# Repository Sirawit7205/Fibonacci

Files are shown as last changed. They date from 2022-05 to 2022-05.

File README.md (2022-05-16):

# Fibonacci
16-bit Fibonacci calculator with logic ICs

A circuit that calculates fibonacci up to 46,368 using only logic chips (except the display).

This project is mostly intended as a soldering practice because the PIC microcontroller featured on the board is fully capable of calculating fibonacci anyway without all the logic chips.

There are two versions of PCB, through-hole and SMD. Both versions use the same circuit and have the same physical size (4x6 inches: will fit most postcard frames).

The only difference is the PIC microcontroller used, both code also work the same way.

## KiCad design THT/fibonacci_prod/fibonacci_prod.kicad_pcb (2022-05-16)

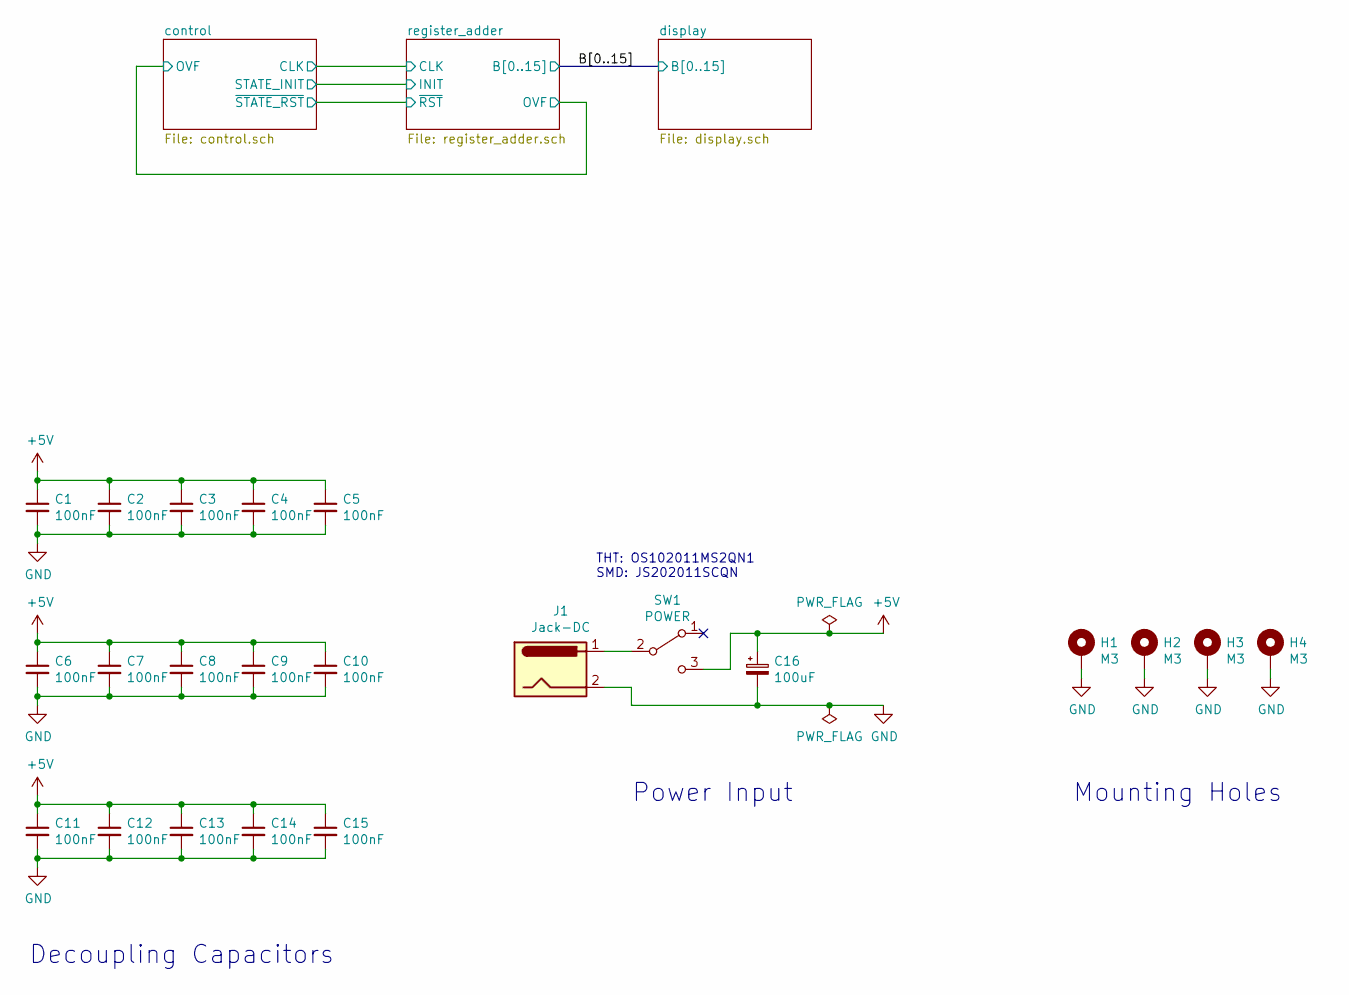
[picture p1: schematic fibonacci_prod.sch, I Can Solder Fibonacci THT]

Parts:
C1, C2, C3, C4, C5, C6, C7, C8, C9, C10, C11, C12, C13, C14, C15: 100nF; C_Disc_D5.1mm_W3.2mm_P5.00mm
C16: 100uF; CP_Radial_D6.3mm_P2.50mm
H1, H2, H3, H4: M3; MountingHole_3mm_Pad
J1: Jack-DC; BarrelJack_Horizontal
SW1: POWER; OS102011MS2QN1

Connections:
+5V: C1.1, C2.1, C3.1, C4.1, C5.1, C6.1, C7.1, C8.1, C9.1, C10.1, C11.1, C12.1, C13.1, C14.1, C15.1, C16.1, SW1.3 (C); also elsewhere on the board
GND: C1.2, C2.2, C3.2, C4.2, C5.2, C6.2, C7.2, C8.2, C9.2, C10.2, C11.2, C12.2, C13.2, C14.2, C15.2, C16.2, H1.1, H2.1, H3.1, H4.1, J1.2; also elsewhere on the board
unnamed: J1.1, SW1.2 (B)

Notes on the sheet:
Decoupling Capacitors
Power Input
THT: OS102011MS2QN1 SMD: JS202011SCQN
Mounting Holes

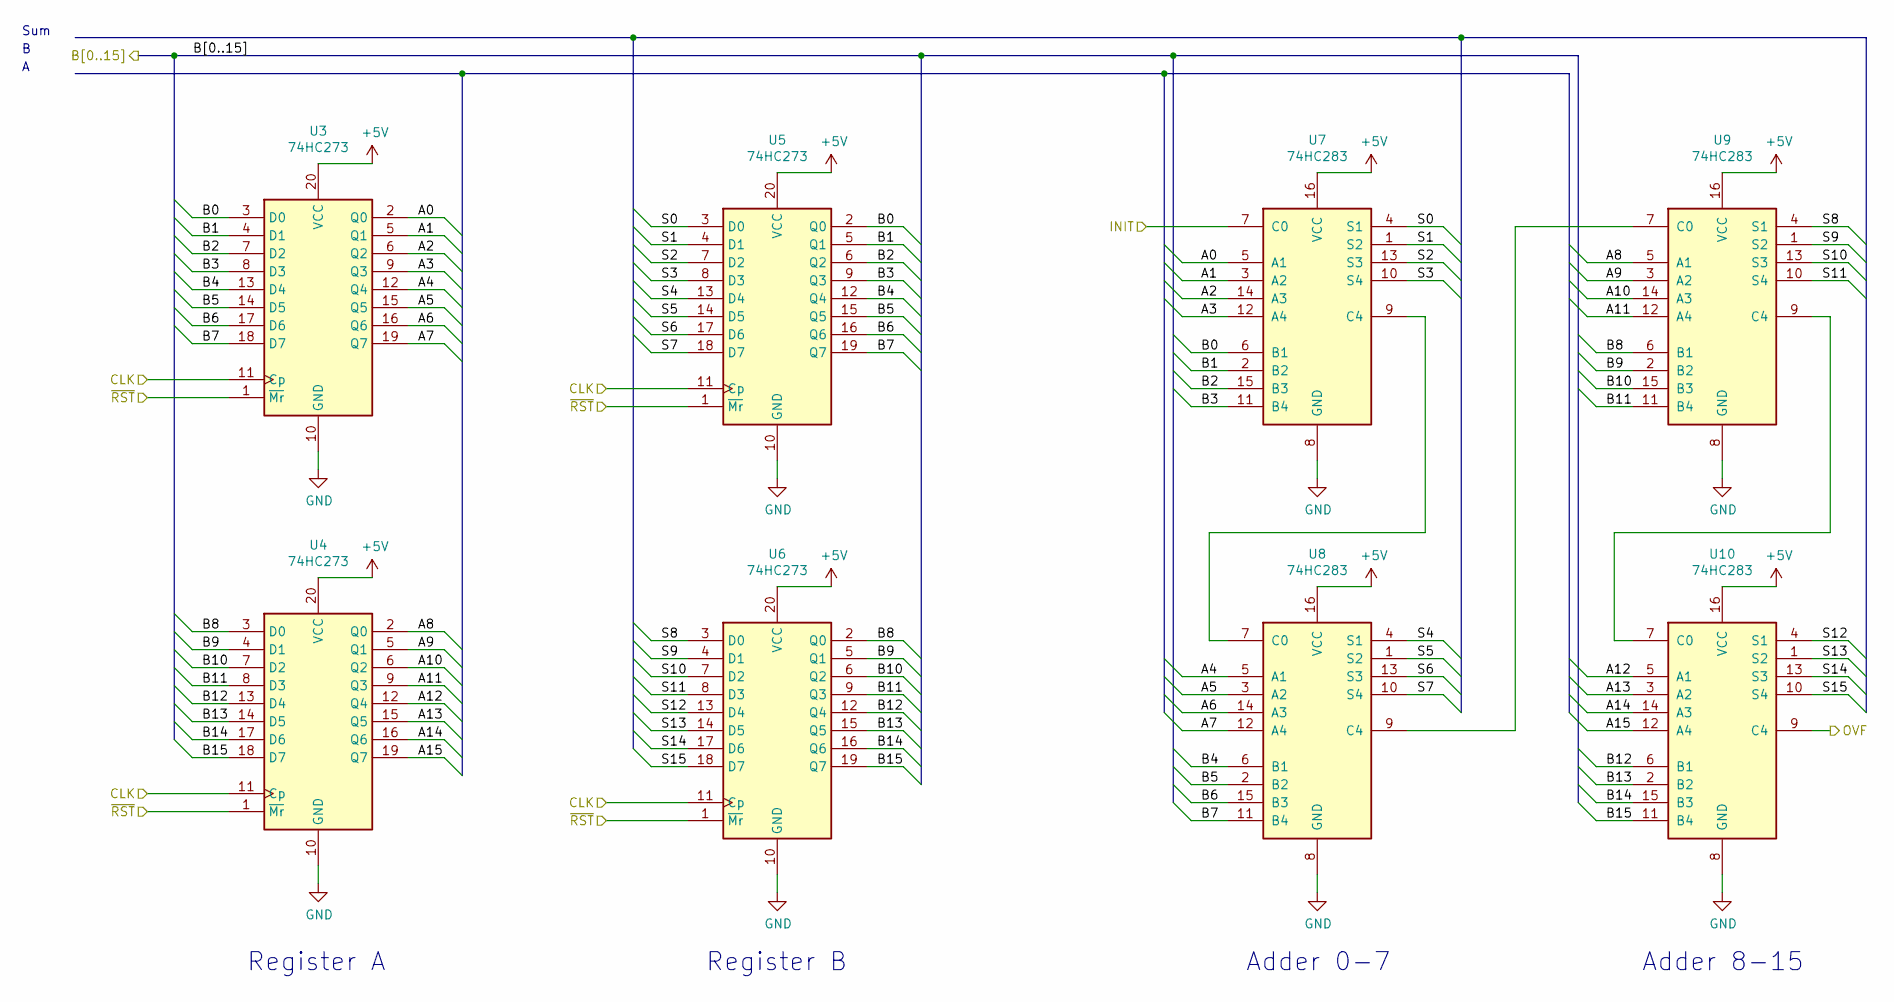
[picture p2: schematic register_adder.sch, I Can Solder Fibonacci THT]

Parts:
U3, U4, U5, U6: 74HC273; DIP-20_W7.62mm
U7, U8, U9, U10: 74HC283; DIP-16_W7.62mm

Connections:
+5V: U3.20 (VCC), U4.20 (VCC), U5.20 (VCC), U6.20 (VCC), U7.16 (VCC), U8.16 (VCC), U9.16 (VCC), U10.16 (VCC); also elsewhere on the board
/control/CLK: U3.11 (Cp), U4.11 (Cp), U5.11 (Cp), U6.11 (Cp); also elsewhere on the board
/control/OVF: U10.9 (C4); also elsewhere on the board
/display/B0: U3.3 (D0), U5.2 (Q0), U7.6 (B1); also elsewhere on the board
/display/B1: U3.4 (D1), U5.5 (Q1), U7.2 (B2); also elsewhere on the board
/display/B2: U3.7 (D2), U5.6 (Q2), U7.15 (B3); also elsewhere on the board
/display/B3: U3.8 (D3), U5.9 (Q3), U7.11 (B4); also elsewhere on the board
/display/B4: U3.13 (D4), U5.12 (Q4), U8.6 (B1); also elsewhere on the board
/display/B5: U3.14 (D5), U5.15 (Q5), U8.2 (B2); also elsewhere on the board
/display/B6: U3.17 (D6), U5.16 (Q6), U8.15 (B3); also elsewhere on the board
/display/B7: U3.18 (D7), U5.19 (Q7), U8.11 (B4); also elsewhere on the board
/display/B8: U4.3 (D0), U6.2 (Q0), U9.6 (B1); also elsewhere on the board
/display/B9: U4.4 (D1), U6.5 (Q1), U9.2 (B2); also elsewhere on the board
/display/B10: U4.7 (D2), U6.6 (Q2), U9.15 (B3); also elsewhere on the board
/display/B11: U4.8 (D3), U6.9 (Q3), U9.11 (B4); also elsewhere on the board
/display/B12: U4.13 (D4), U6.12 (Q4), U10.6 (B1); also elsewhere on the board
/display/B13: U4.14 (D5), U6.15 (Q5), U10.2 (B2); also elsewhere on the board
/display/B14: U4.17 (D6), U6.16 (Q6), U10.15 (B3); also elsewhere on the board
/display/B15: U4.18 (D7), U6.19 (Q7), U10.11 (B4); also elsewhere on the board
/register_adder/A0: U3.2 (Q0), U7.5 (A1)
/register_adder/A1: U3.5 (Q1), U7.3 (A2)
/register_adder/A2: U3.6 (Q2), U7.14 (A3)
/register_adder/A3: U3.9 (Q3), U7.12 (A4)
/register_adder/A4: U3.12 (Q4), U8.5 (A1)
/register_adder/A5: U3.15 (Q5), U8.3 (A2)
/register_adder/A6: U3.16 (Q6), U8.14 (A3)
/register_adder/A7: U3.19 (Q7), U8.12 (A4)
/register_adder/A8: U4.2 (Q0), U9.5 (A1)
/register_adder/A9: U4.5 (Q1), U9.3 (A2)
/register_adder/A10: U4.6 (Q2), U9.14 (A3)
/register_adder/A11: U4.9 (Q3), U9.12 (A4)
/register_adder/A12: U4.12 (Q4), U10.5 (A1)
/register_adder/A13: U4.15 (Q5), U10.3 (A2)
/register_adder/A14: U4.16 (Q6), U10.14 (A3)
/register_adder/A15: U4.19 (Q7), U10.12 (A4)
/register_adder/INIT: U7.7 (C0); also elsewhere on the board
/register_adder/S0: U5.3 (D0), U7.4 (S1)
/register_adder/S1: U5.4 (D1), U7.1 (S2)
/register_adder/S2: U5.7 (D2), U7.13 (S3)
/register_adder/S3: U5.8 (D3), U7.10 (S4)
/register_adder/S4: U5.13 (D4), U8.4 (S1)
/register_adder/S5: U5.14 (D5), U8.1 (S2)
/register_adder/S6: U5.17 (D6), U8.13 (S3)
/register_adder/S7: U5.18 (D7), U8.10 (S4)
/register_adder/S8: U6.3 (D0), U9.4 (S1)
/register_adder/S9: U6.4 (D1), U9.1 (S2)
/register_adder/S10: U6.7 (D2), U9.13 (S3)
/register_adder/S11: U6.8 (D3), U9.10 (S4)
/register_adder/S12: U6.13 (D4), U10.4 (S1)
/register_adder/S13: U6.14 (D5), U10.1 (S2)
/register_adder/S14: U6.17 (D6), U10.13 (S3)
/register_adder/S15: U6.18 (D7), U10.10 (S4)
/register_adder/~RST: U3.1 (~Mr), U4.1 (~Mr), U5.1 (~Mr), U6.1 (~Mr); also elsewhere on the board
GND: U3.10 (GND), U4.10 (GND), U5.10 (GND), U6.10 (GND), U7.8 (GND), U8.8 (GND), U9.8 (GND), U10.8 (GND); also elsewhere on the board
unnamed: U7.9 (C4), U8.7 (C0)
unnamed: U8.9 (C4), U9.7 (C0)
unnamed: U9.9 (C4), U10.7 (C0)

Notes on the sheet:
Adder 0-7
Adder 8-15
Register B
Register A
Sum

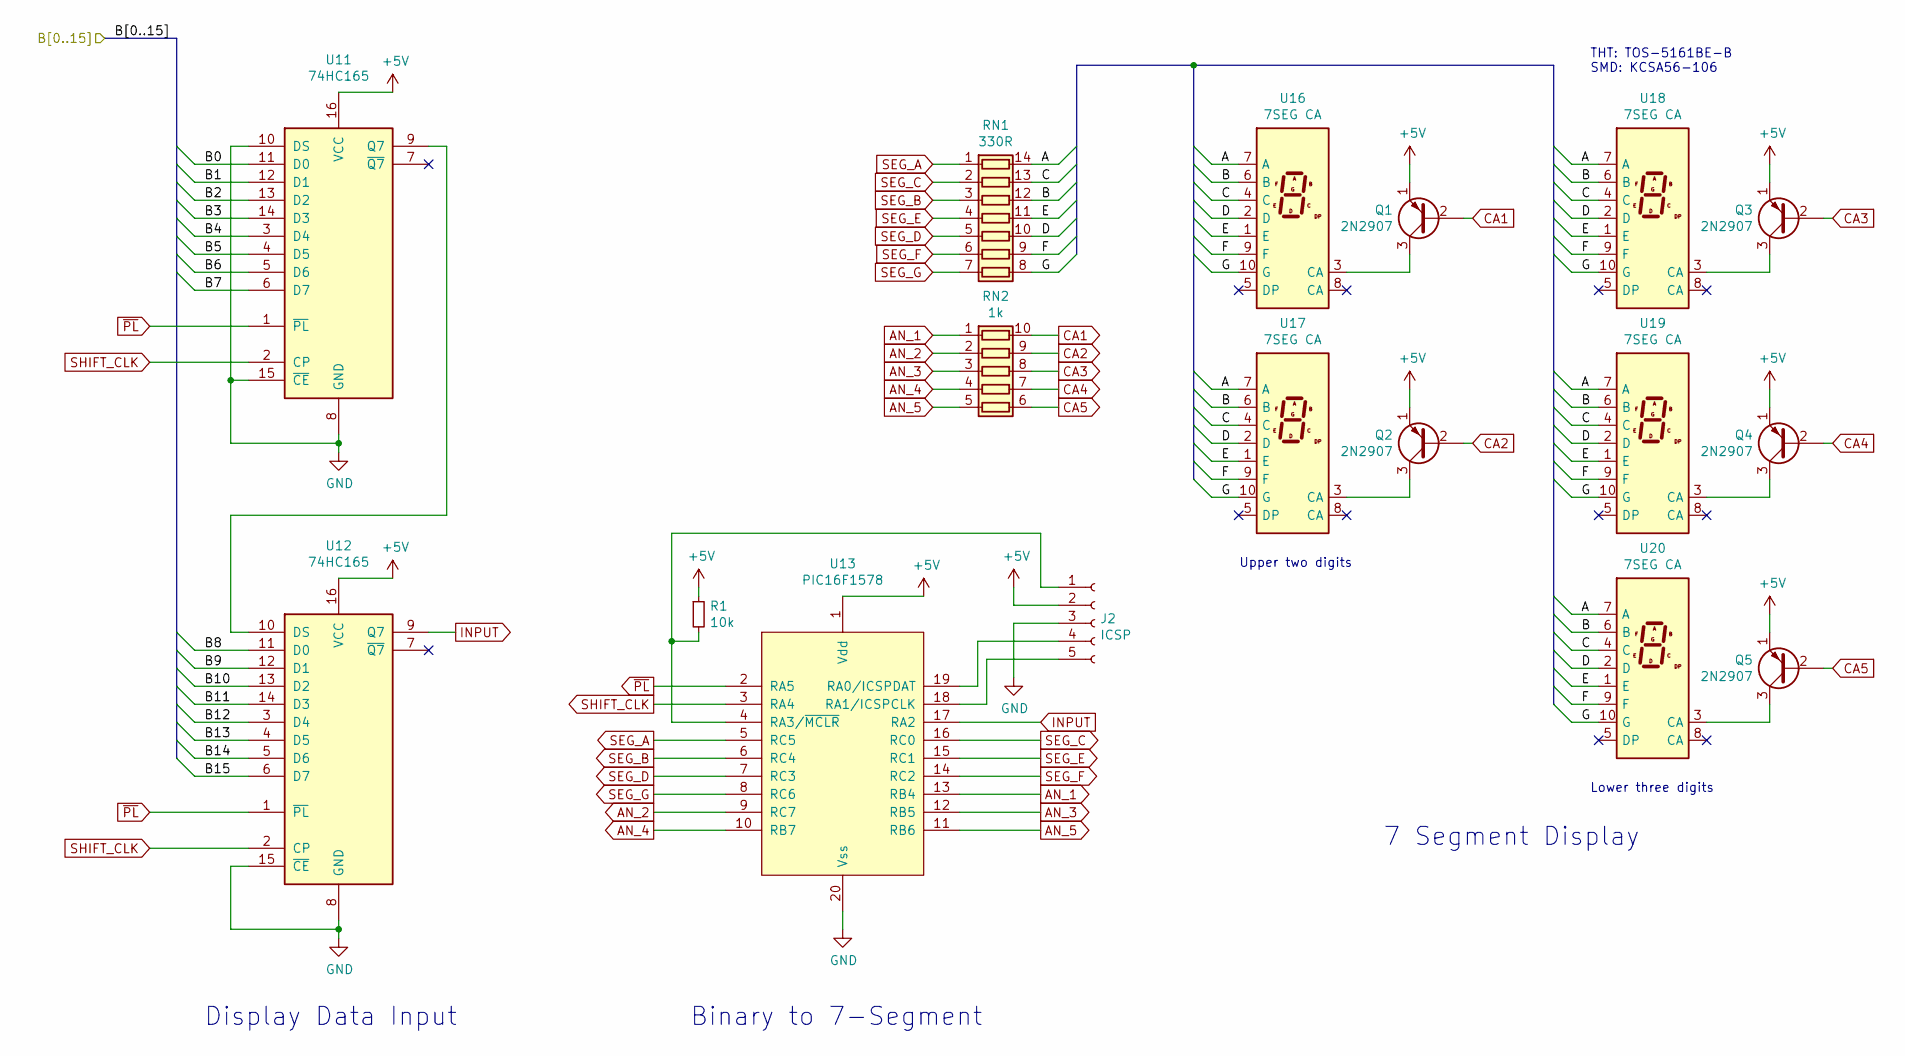
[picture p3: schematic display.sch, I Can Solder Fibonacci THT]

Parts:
J2: ICSP; PinHeader_1x05_P2.54mm_Vertical
Q1, Q2, Q3, Q4, Q5: 2N2907; TO-92
R1: 10k; R_Axial_DIN0207_L6.3mm_D2.5mm_P7.62mm_Horizontal
RN1: 330R; DIP-14_W7.62mm_Socket
RN2: 1k; DIP-10_W7.62mm_Socket
U11, U12: 74HC165; DIP-16_W7.62mm
U13: PIC16F1578; DIP-20_W7.62mm
U16, U17, U18, U19, U20: 7SEG CA; 7SegmentLED_LTS6760_LTS6780

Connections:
+5V: J2.2, Q1.1 (E), Q2.1 (E), Q3.1 (E), Q4.1 (E), Q5.1 (E), R1.1, U11.16 (VCC), U12.16 (VCC), U13.1 (Vdd); also elsewhere on the board
/display/A: RN1.14 (R1.2), U16.7 (A), U17.7 (A), U18.7 (A), U19.7 (A), U20.7 (A)
/display/B: RN1.12 (R3.2), U16.6 (B), U17.6 (B), U18.6 (B), U19.6 (B), U20.6 (B)
/display/B0: U11.11 (D0); also elsewhere on the board
/display/B1: U11.12 (D1); also elsewhere on the board
/display/B2: U11.13 (D2); also elsewhere on the board
/display/B3: U11.14 (D3); also elsewhere on the board
/display/B4: U11.3 (D4); also elsewhere on the board
/display/B5: U11.4 (D5); also elsewhere on the board
/display/B6: U11.5 (D6); also elsewhere on the board
/display/B7: U11.6 (D7); also elsewhere on the board
/display/B8: U12.11 (D0); also elsewhere on the board
/display/B9: U12.12 (D1); also elsewhere on the board
/display/B10: U12.13 (D2); also elsewhere on the board
/display/B11: U12.14 (D3); also elsewhere on the board
/display/B12: U12.3 (D4); also elsewhere on the board
/display/B13: U12.4 (D5); also elsewhere on the board
/display/B14: U12.5 (D6); also elsewhere on the board
/display/B15: U12.6 (D7); also elsewhere on the board
/display/C: RN1.13 (R2.2), U16.4 (C), U17.4 (C), U18.4 (C), U19.4 (C), U20.4 (C)
/display/D: RN1.10 (R5.2), U16.2 (D), U17.2 (D), U18.2 (D), U19.2 (D), U20.2 (D)
/display/E: RN1.11 (R4.2), U16.1 (E), U17.1 (E), U18.1 (E), U19.1 (E), U20.1 (E)
/display/F: RN1.9 (R6.2), U16.9 (F), U17.9 (F), U18.9 (F), U19.9 (F), U20.9 (F)
/display/G: RN1.8 (R7.2), U16.10 (G), U17.10 (G), U18.10 (G), U19.10 (G), U20.10 (G)
AN_1: RN2.1 (R1.1), U13.13 (RB4)
AN_2: RN2.2 (R2.1), U13.9 (RC7)
AN_3: RN2.3 (R3.1), U13.12 (RB5)
AN_4: RN2.4 (R4.1), U13.10 (RB7)
AN_5: RN2.5 (R5.1), U13.11 (RB6)
CA1: Q1.2 (B), RN2.10 (R1.2)
CA2: Q2.2 (B), RN2.9 (R2.2)
CA3: Q3.2 (B), RN2.8 (R3.2)
CA4: Q4.2 (B), RN2.7 (R4.2)
CA5: Q5.2 (B), RN2.6 (R5.2)
GND: J2.3, U11.8 (GND), U11.10 (DS), U11.15 (~CE), U12.8 (GND), U12.15 (~CE), U13.20 (Vss); also elsewhere on the board
INPUT: U12.9 (Q7), U13.17 (RA2)
unnamed: J2.1, R1.2, U13.4 (RA3/~MCLR)
unnamed: J2.4, U13.19 (RA0/ICSPDAT)
unnamed: J2.5, U13.18 (RA1/ICSPCLK)
unnamed: Q1.3 (C), U16.3 (CA)
unnamed: Q2.3 (C), U17.3 (CA)
unnamed: Q3.3 (C), U18.3 (CA)
unnamed: Q4.3 (C), U19.3 (CA)
unnamed: Q5.3 (C), U20.3 (CA)
unnamed: U11.9 (Q7), U12.10 (DS)
SEG_A: RN1.1 (R1.1), U13.5 (RC5)
SEG_B: RN1.3 (R3.1), U13.6 (RC4)
SEG_C: RN1.2 (R2.1), U13.16 (RC0)
SEG_D: RN1.5 (R5.1), U13.7 (RC3)
SEG_E: RN1.4 (R4.1), U13.15 (RC1)
SEG_F: RN1.6 (R6.1), U13.14 (RC2)
SEG_G: RN1.7 (R7.1), U13.8 (RC6)
SHIFT_CLK: U11.2 (CP), U12.2 (CP), U13.3 (RA4)
~PL: U11.1 (~PL), U12.1 (~PL), U13.2 (RA5)

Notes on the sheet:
THT: TOS-5161BE-B SMD: KCSA56-106
Upper two digits
Lower three digits
7 Segment Display
Display Data Input
Binary to 7-Segment

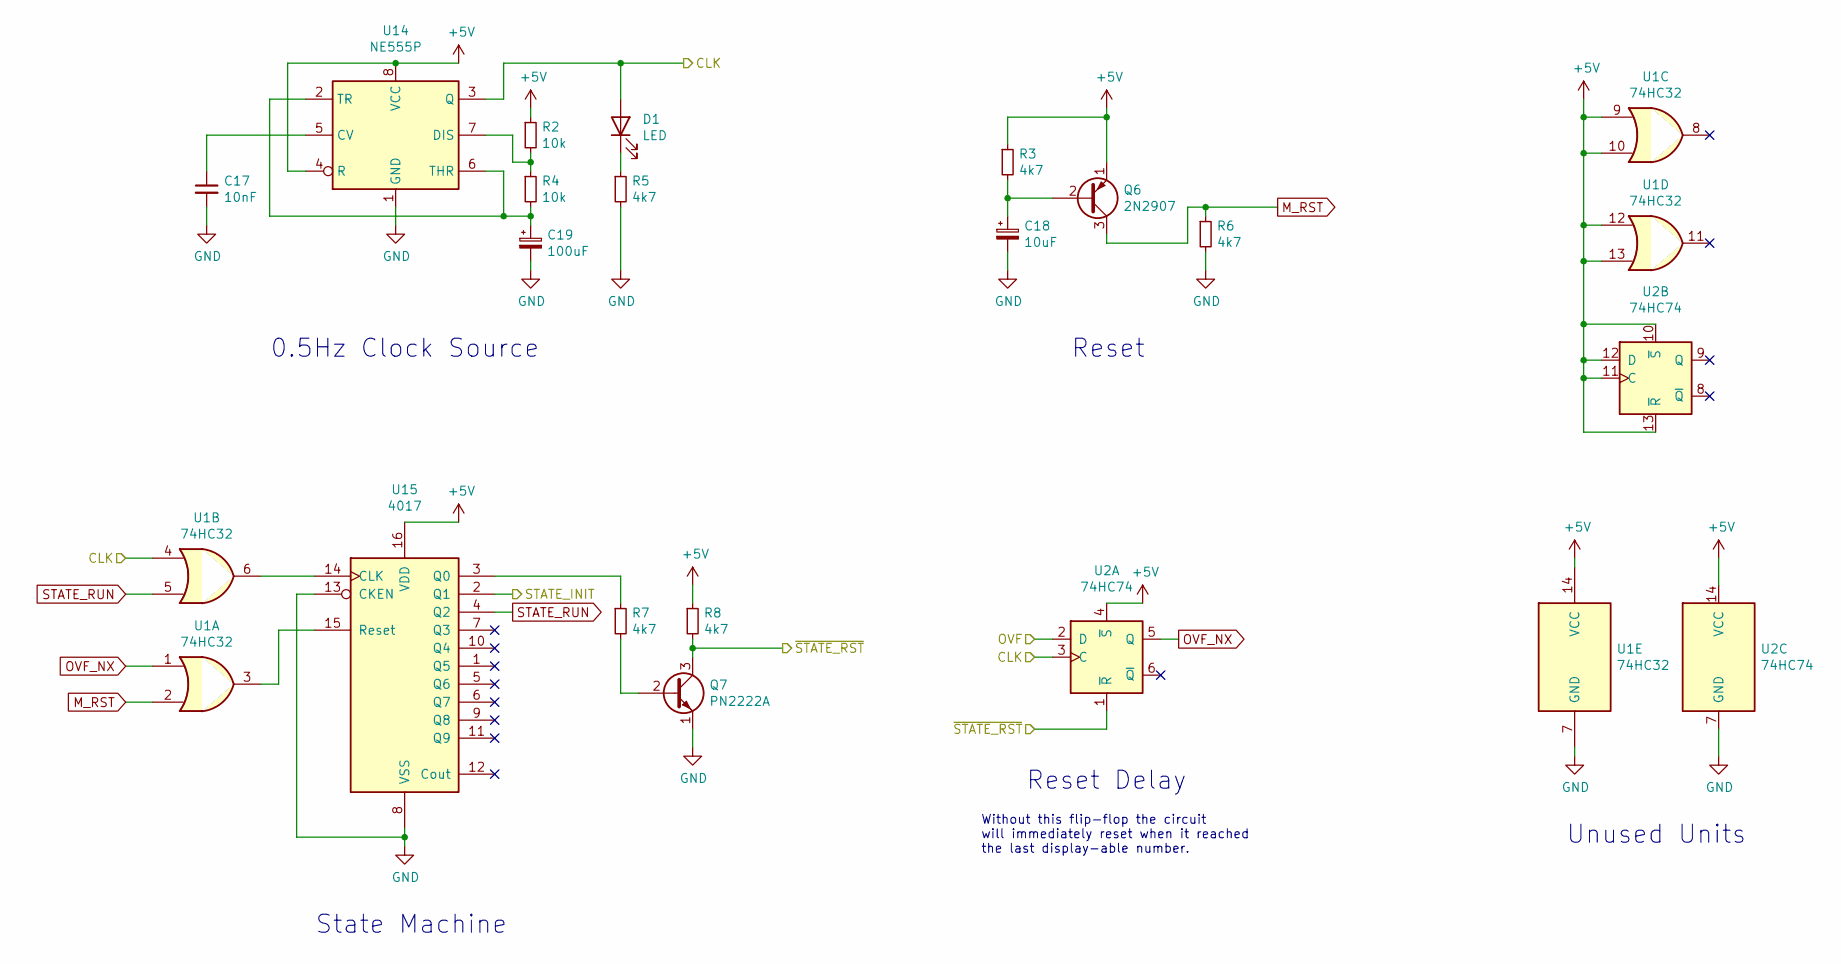
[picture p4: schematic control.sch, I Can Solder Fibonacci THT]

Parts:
C17: 10nF; C_Disc_D5.1mm_W3.2mm_P5.00mm
C18: 10uF; CP_Radial_D5.0mm_P2.00mm
C19: 100uF; CP_Radial_D6.3mm_P2.50mm
D1: LED; LED_D3.0mm
Q6: 2N2907; TO-92
Q7: PN2222A; TO-92
R2, R4: 10k; R_Axial_DIN0207_L6.3mm_D2.5mm_P2.54mm_Vertical
R3, R6: 4k7; R_Axial_DIN0207_L6.3mm_D2.5mm_P2.54mm_Vertical
R5, R7, R8: 4k7; R_Axial_DIN0207_L6.3mm_D2.5mm_P7.62mm_Horizontal
U1: 74HC32; DIP-14_W7.62mm
U2: 74HC74; DIP-14_W7.62mm
U14: NE555P; DIP-8_W7.62mm
U15: 4017; DIP-16_W7.62mm

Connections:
+5V: Q6.1 (E), R2.1, R3.1, R8.1, U1.9, U1.10, U1.12, U1.13, U1.14 (VCC), U2.4 (~S), U2.10 (~S), U2.11 (C), U2.12 (D), U2.13 (~R), U2.14 (VCC), U14.4 (R), U14.8 (VCC), U15.16 (VDD); also elsewhere on the board
/control/CLK: D1.2 (A), U1.4, U2.3 (C), U14.3 (Q); also elsewhere on the board
/control/OVF: U2.2 (D); also elsewhere on the board
/register_adder/INIT: U15.2 (Q1); also elsewhere on the board
/register_adder/~RST: Q7.3 (C), R8.2, U2.1 (~R); also elsewhere on the board
GND: C17.2, C18.2, C19.2, Q7.1 (E), R5.2, R6.2, U1.7 (GND), U2.7 (GND), U14.1 (GND), U15.8 (VSS), U15.13 (CKEN); also elsewhere on the board
M_RST: Q6.3 (C), R6.1, U1.2
unnamed: C17.1, U14.5 (CV)
unnamed: C18.1, Q6.2 (B), R3.2
unnamed: C19.1, R4.2, U14.2 (TR), U14.6 (THR)
unnamed: D1.1 (K), R5.1
unnamed: Q7.2 (B), R7.2
unnamed: R2.2, R4.1, U14.7 (DIS)
unnamed: R7.1, U15.3 (Q0)
unnamed: U1.3, U15.15 (Reset)
unnamed: U1.6, U15.14 (CLK)
OVF_NX: U1.1, U2.5 (Q)
STATE_RUN: U1.5, U15.4 (Q2)

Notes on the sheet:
0.5Hz Clock Source
Reset
State Machine
Reset Delay
Without this flip-flop the circuit will immediately reset when it reached the last display-able number.
Unused Units

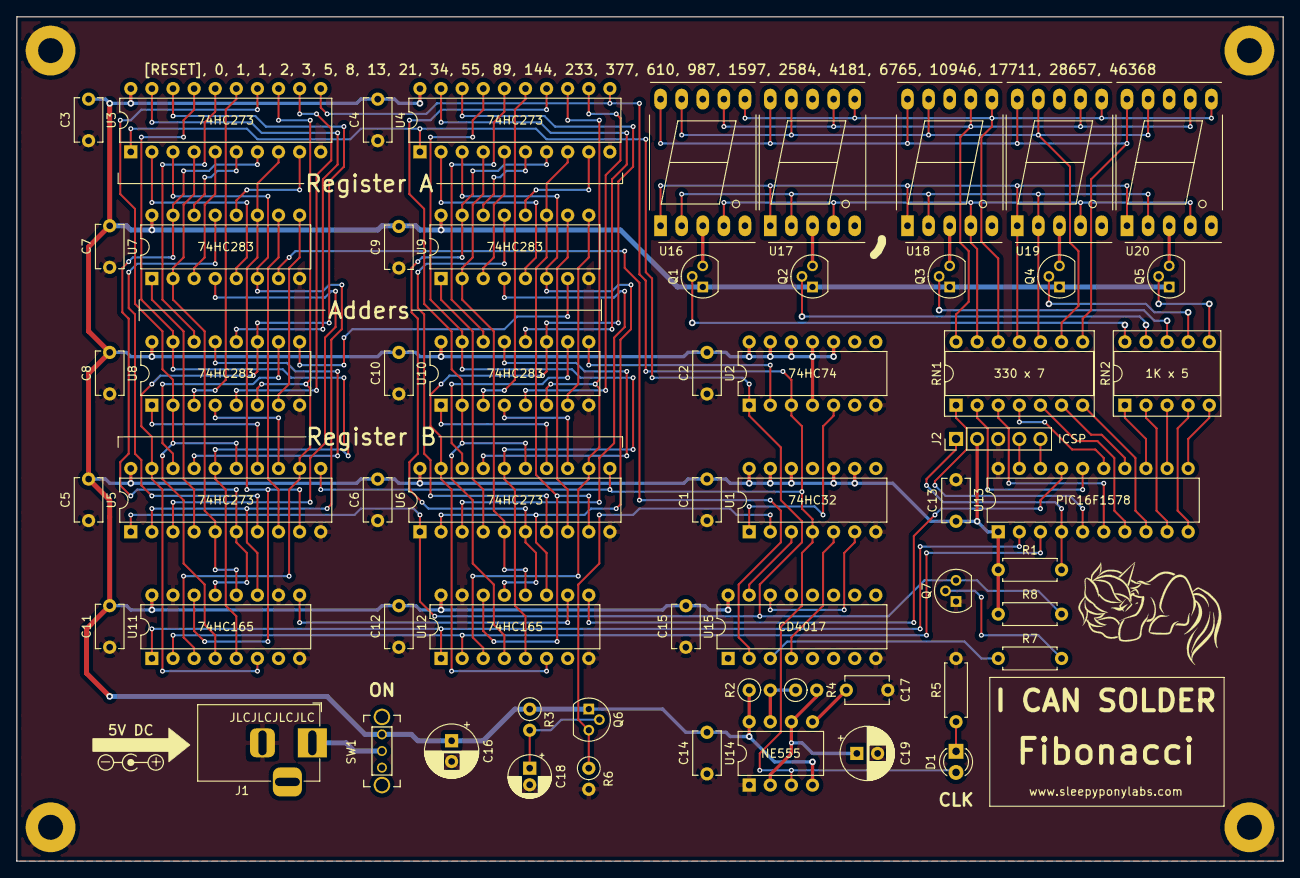
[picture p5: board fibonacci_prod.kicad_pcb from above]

Board: 2 copper layers, 152.4 x 101.6 mm, 64 parts (0 on the bottom side), 106 nets.

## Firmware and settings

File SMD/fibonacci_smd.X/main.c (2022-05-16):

/*
 *  7-segment multiplexing
 * 
 *  RA0 = ICSPDAT
 *  RA1 = ICSPCLK
 *  RA2 = Serial input
 *  RA3 = MCLR
 *  RA4 = Shift clock
 *  RA5 = Parallel load
 *  RB4 = Anode 1
 *  RB5 = Anode 3
 *  RB6 = Anode 5
 *  RB7 = Anode 4
 *  RC7 = Anode 2
 *  
 *  PORTC = Cathode (-,G,A,B,D,F,E,C)
 */

// PIC16F721 Configuration Bit Settings

// 'C' source line config statements

// CONFIG1
#pragma config FOSC = INTOSCIO  // Oscillator Selection bits (INTOSCIO oscillator: I/O function on RA4/CLKO pin, I/O function on RA5/CLKI)
#pragma config WDTE = ON        // Watchdog Timer Enable bit (WDT enabled)
#pragma config PWRTE = OFF      // Power-up Timer Enable bit (PWRT disabled)
#pragma config MCLRE = ON       // RA3/MCLR/VPP Pin Function Select bit (RA3/MCLR/VPP pin function is MCLR; Weak pull-up enabled.)
#pragma config CP = OFF         // Flash Program Memory Code Protection bit (Code protection off)
#pragma config BOREN = ON       // Brown-out Reset Enable bits (Brown-out Reset enabled)
#pragma config PLLEN = ON       // INTOSC PLLEN Enable Bit (INTOSC Frequency is 16 MHz (32x))

// CONFIG2
#pragma config WRTEN = OFF      // Flash memory self-write protection bits (Write protection off)

// #pragma config statements should precede project file includes.
// Use project enums instead of #define for ON and OFF.

#define _XTAL_FREQ 4000000

#include <xc.h>
#include <stdint.h>

unsigned char digits[10] = {0xC0, 0xEE, 0x85, 0x86, 0xAA, 0x92, 0x90, 0xCA, 0x80, 0x82};

#define PL RA5
#define SCLK RA4
#define SDAT RA2
#define AN1 RB4
#define AN2 RC7
#define AN3 RB5
#define AN4 RB7
#define AN5 RB6

uint16_t getNumber() {
    uint16_t output = 0;
    
    //parallel load
    PL = 0;
    __delay_us(1);
    PL = 1;
    __delay_us(1);
    
    for(int i = 0; i < 16; i++) {
        //shift current bit in
        output = (output << 1) | SDAT;
        
        //shift next bit out
        SCLK = 1;
        __delay_us(1);
        SCLK = 0;
        __delay_us(1);
    }
    
    return output;
}

void main(void) {
    //chip setup
    OSCCON |= _OSCCON_IRCF0_MASK;               //set INTOSC speed to 4 MHz
    OSCCON &= ~_OSCCON_IRCF1_MASK;
    OPTION_REG &= ~_OPTION_REG_nRABPU_MASK;     //global enable port pull-ups
    WPUA |= _WPUA_WPUA2_MASK;                   //enable pull-up on RA2
    ANSELA &= 0x00;                             //disable analog input on all ports
    ANSELB &= 0x00;
    ANSELC &= 0x00;
    TRISA &= 0x04;                              //port A as output except RA2
    TRISB &= 0x00;                              //port B as output
    TRISC &= 0x00;                              //port C as output
    PORTA |= 0xEB;                              //port A all high except RA2, RA4 (shift clock low, parallel load high)
    PORTB |= 0xFF;                              //port B all high (disable anodes)
    PORTC |= 0xFF;                              //port C all high (disable cathodes and anode 2)

    while(1)
    {
        asm("CLRWDT");  //clear WDT
        
        uint16_t num = getNumber();
        
        //digit 1
        PORTC = digits[num / 10000];
        num = num % 10000;
        AN1 = 0;
        __delay_ms(2);
        AN1 = 1;

        //digit 2
        PORTC = digits[num / 1000];
        num = num % 1000;
        AN2 = 0;
        __delay_ms(2);
        AN2 = 1;
        
        //digit 3
        PORTC = digits[num / 100];
        num = num % 100;
        AN3 = 0;
        __delay_ms(2);
        AN3 = 1;

        //digit 4
        PORTC = digits[num / 10];
        num = num % 10;
        AN4 = 0;
        __delay_ms(2);
        AN4 = 1;

        //digit 5
        PORTC = digits[num];
        AN5 = 0;
        __delay_ms(2);
        AN5 = 1;
    }
    
    return;
}
